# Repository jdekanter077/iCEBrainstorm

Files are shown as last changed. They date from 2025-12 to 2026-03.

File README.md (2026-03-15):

# iCEBrainstorm

A STM32F412 MCU with a iCE40UP5K FPGA on a compact dev board.

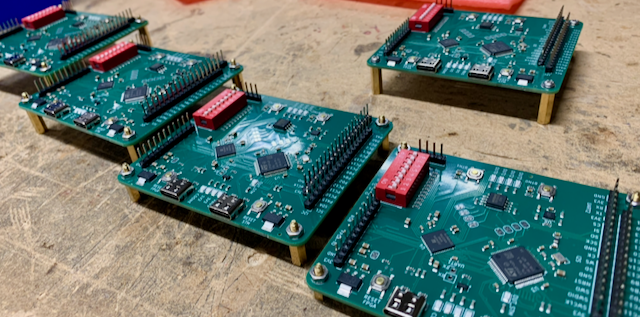
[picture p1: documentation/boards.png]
boards


You will need STMCubeMX, VSCode with the STM32Cube Extension and STMCubeProgrammer to program the STM.

<!-- You can use [apio](https://github.com/FPGAwars/apio) to synthesise a design and upload the firmware to the FPGA using a [online dfu-uploader](https://devanlai.github.io/webdfu/dfu-util/) (easier) -->

<!-- You will need to use the [oss-cad-suite](https://github.com/YosysHQ/oss-cad-suite-build) to to synthesise your design and upload the bitstream to the FPGA.  -->
You can use apio to synthesize and upload your hdl on the FPGA. Refer to [apio support](#apio-support) on how to configure apio to support the iCEBrainstorm board.

## Basic Structure
The STM32 Microcontroller and the iCE40 FPGA share one PCB and have some connections between them to communicate.
They can be programmed through their respective USB-C Port.
There are some switches to select the "program mode" for both the STM and the FPGA.

The code and bootloader of the SMT are stored inside the SMT IC, but the code and bootloader of the FPGA are stored on an external SPI Flash IC. 

There is also an gyrosensor on board. For more documentation, go look at the KiCAD files.

<!-- ![](/documentation/foto.png) -->

## How to Program:
Both the STM and the FPGA use a "Bootloader" to re-program themselfes. This makes the device visible to your computer and puts it in "program mode".

### STM32
The STM32 relies on its build-in bootloader to program itself via USB.
The bootloader is selected by switching the ```BOOT0``` Switch and ```RESET```-ing the SMT:
- Set the ```BOOT0``` Switch
- press ```RESET STM``` or plug in the cable
- The STM is now in DFU-mode, and can be programmed with STM32CubeProgrammer (or other software)
- In CubeProgrammer: select USB and click connect

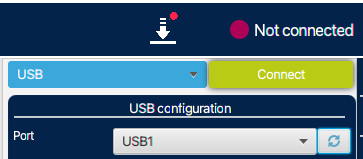
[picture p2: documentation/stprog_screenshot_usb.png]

- Click ```Open File``` and select your ```.elf``` file


- Click ```Download```


- Reset the ```BOOT0``` Switch.
- press ```RESET STM``` and your code should run.

### ICE40 FPGA

The FPGA relies on the [no2 bootloader](https://github.com/psychogenic/no2bootloader/tree/master), which is stored on the SPI-Flash IC.
The bootloader is selected by switching the ```FBOOT``` switch and ```RESET```-ing the FPGA, and then putting the ```FBOOT``` switch back.
Check if the ```CDONE``` LED at the top of the board is on.

- Set the ```FBOOT``` Switch
- press ```RESET FPGA``` or plug in the cable
- Reset the ```BOOT0``` Switch.
- Check if the ```CDONE``` LED at the top of the board is on.
- The FPGA is now in DFU-mode, and can be programmed with 
```apio upload``` or using ```dfu-util```

<!-- - run ```dfu-util -l``` to list all dfu devices. -->
<!-- example output: 
```Found DFU: [1d50:6146] ver=0006, devnum=12, cfg=1, intf=0, path="", alt=1, name="RISC-V firmware", serial="e464bc68932e5839"
Found DFU: [1d50:6146] ver=0006, devnum=12, cfg=1, intf=0, path="", alt=0, name="iCE40 bitstream", serial="e464bc68932e5839"
``` -->
<!-- - run ```dfu-util -d 1d50:6146 -a 0 -D hardware.bin``` to flash your bitstream on the FPGA. Maybe You have to replace the ```1d50:6146```-number with what you see on your terminal. -->
- you can run ```apio devices usb``` to list all dfu devices and verify that everything works.
- run ```apio upload``` to synthesize and upload the verilog code.

-  To edit your HDL code, take a look at the examples in [software/FPGA](./software/FPGA)

### APIO Support
[apio](https://github.com/FPGAwars/apio) is a open-source FPGA Toolchain, which will help us synthesize HDL code.
Make sure you have a recent version of apio installed! You can uninstall and install again to update.
- Install apio using ```pip install apio```
- edit ```~/.apio/packages/definitions/boards.jsonc``` and add this snippet:
```
  // https://github.com/jdekanter077/iCEBrainstorm
  "iCEBrainstorm": {
    "legacy-name": "iCEBrainstorm",
    "description": "iCEBrainstorm by jdk",
    "fpga-id": "ice40up5k-sg48",
    "programmer": {
      "id": "dfu"
    },
    "usb": {
      "vid": "1d50",
      "pid": "6146"
    }
  },
```

This will add apio support for the iCEBrainstorm board.
-  to create a new project, run ```apio create -b iCEBrainstorm```
-  edit your HDL code, take a look at the examples in [software/FPGA](./software/FPGA)

### Bootloader
The Bootloader is preinstalled by Joël and should not have to be touched.
Check out [bootloader/README.md](./software/FPGA/bootloader/README.md) for more information.

## Setting up a blank Project
### STM
- Open CubeMX and select ```File -> New Project```.
- In ```Commercial Part Number```, Type ```STM32F412RET6TR``` and select ```Start Project```.
![](./documentation/stcubemx_newproj.png)
- Select ```RCC_MCO_2``` on ```PB9``` to provide a Clock signal to the FPGA
- Select your desired pins, for example ```PB5```, which is connected to the on-board LED and select ```GPIO_Output```.
![](./documentation/stcubemx_pins.png)
- On the left Pane in ```System Core -> GPIO -> PB5``` set a user label, for example ```OUT_STM```
![](./documentation/stcubemx_gpio.png)
- Set the Input Clock to Cyrstal Oscillator in ```System Core -> RCC```
![](./documentation/stcubemx_sys_clock.png)
- Got to ```Clock Configuration``` at the top and set the Input Frequency of the Clock to 16 MHz
![](./documentation/stcubemx_clock_tree.png)
- Go to ```Project Manager``` on the top.
Make sure to select ```CMake``` as the ```Toolchain / IDE```.
![](./documentation/stcubemx_projman1.png)
Make sure to set ```Generate ... as pair of '.c/.h' files ...```
![](./documentation/stcubemx_projman2.png)

- Save your project and click ```GENRATE CODE``` in the top right and open the folder in VSCode

- Make sure to not miss the notification to "configure CMake Projects as STM32 Projects". click Yes.
![](documentation/vscode_notification.png)

- Select a Preset from the Popup (Debug)
- Edit the Code, for example, add blinky loop in ```Core/Src/main.c```
- ```line 98```:

```
/* USER CODE BEGIN WHILE */
while (1)
  {
    HAL_GPIO_TogglePin(OUT_STM_GPIO_Port, OUT_STM_Pin);
    HAL_Delay(100);
    /* USER CODE END WHILE */

    /* USER CODE BEGIN 3 */
  }
  /* USER CODE END 3 */
}
```
- To Compile the code, go to ```Run & Debug -> Run & Debug -> STM32Cube: STLink GDB Server```

![](documentation/vscode_compile.png)
- This will compile the code, and try to start a "debugger", which is not available and gives a error. The Code should still be compiled correctly!
- Check if you have a ```.elf``` file in ```build/Debug/```. Upload this to the iCEBrainstorm using the steps described in [how-to-programm](#how-to-program)

## Clock
The STM and the FPGA are relatively independent from each other, with one slight caveat:
The STM32 is responsible for providing the FPGA with a Clock signal. The no2-bootloader of the FPGA relies on this clock source, and will not work without it. 

This clock can of course be used in your FPGA design as well.

### How to provide the clock 
- In cubeMX, go to ```PC9``` and select ```RCC_MCO_2```

![](/documentation/stcubemx_rcc_mco_2.png)
- Generate Code, open the folder in STMCubeIDE or VSCode, compile, and upload using STMCubeProgrammer.
- Done!

## FPGA Pinout Description:
These informations should be in every ```main.pcf``` file.

| Description | FPGA Pin | Usage |
| --- | ---- | ---- |
| clk_i | 20  | 16 MHz Clock, provided by the STM32 | 
| btn_0 | 31 | left button | 
| btn_1 | 32 | right button | 
| in_0 | 34 | Input Switch and/or GPIO | 
| in_1 | 35 | Input Switch and/or GPIO | 
| in_2 | 36 | Input Switch and/or GPIO | 
| in_3 | 37 | Input Switch and/or GPIO | 
| out_0 | 25  | LED | 
| out_1 | 26  | LED | 
| out_2 | 27  | LED | 
| out_3 | 28  | LED | 
| io_0 | 47  | GPIO | 
| io_1 | 42  | GPIO | 
| io_2 | 38  | GPIO | 
| io_3 | 23  | GPIO | 
| rgb_0 | 39 | RGB LED and/or GPIO | 
| rgb_1 | 40 | RGB LED and/or GPIO | 
| rgb_2 | 41 | RGB LED and/or GPIO | 
| uart_tx | 2  | uart output (STM RX <- FPGA TX) | 
| uart_rx | 3  | uart input (STM TX -> FPGA RX) | 
| scl | 19 | I2C Clock | 
| sda | 18 | I2C Data | 

# Examples

## FPGA & STM: Morse Encoder
This project implements Morse encoder. The FPGA encodes the Morse Code, and sends the encoded character over UART to the STM.
The STM then sends the recieved character over USB to the host machine.

- upload ```./software/STM/uart_serial_bridge``` to the STM.
- upload ```./software/FPGA/morse_uart``` to the FPGA.
- open a serial monitor and have fun!

for details: take a look at the [Readme](./software/FPGA/morse_uart/README.md)

## STM: uart-serial Bridge

This project implements a UART-Serial bridge. The STM sends all recieved uart messages over usb to the host machine, and sends all recieved usb messages over usb to the FPGA.
This is done by using an Interrupt-driven approach.

snippet:

## FPGA: bram
[bram](./software/FPGA/bram)

This example of how to instintiate a one of the build-in BRAMs on the FPGA is based on [this repo](https://github.com/damdoy/ice40_ultraplus_examples/tree/master/bram) and on the [online documentation](https://www.latticesemi.com/~/media/LatticeSemi/Documents/ApplicationNotes/MO/MemoryUsageGuideforiCE40Devices.pdf)
It uses the switches IN0-IN3 as input "data" and loads it into the bram using btn0. Using btn1, the "data" can then be displayed on the leds.

# Author
Joël de Kanter

# License

This repository is primarily licensed under the GNU General Public License v3.0.

Exceptions:
- STM32CubeMX-generated files are licensed under STMicroelectronics'
  STM32Cube firmware license (see file headers).
- The NO2 bootloader firmware is licensed under GPL-3.0-or-later
- Some third-party components may be licensed under MIT or CERN OHL v2.

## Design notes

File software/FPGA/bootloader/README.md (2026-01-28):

# BOOTLOADER

The FPGA relies on the no2bootloader to make itself flashable over USB.

This process was inspired by a [youtube video](https://www.youtube.com/watch?v=gGN0g9jgsUc)

## How to build the bootloader
### Installing depencies
Don't even try building when until these are installed and can be called from your terminal!
- install the [oss-cad-suite](https://github.com/YosysHQ/oss-cad-suite-build)
- install a [embedded riscv compiler (xpack)](https://xpack-dev-tools.github.io/riscv-none-elf-gcc-xpack/)
- for the riscv-compiler, you'll need [xpm](https://xpack.github.io/xpm/)
- and for that, you'll need [npn](https://docs.npmjs.com/cli/v11/configuring-npm/install)

### make sure to set the $PATH
example:
```
export PATH=$PATH:/Users/oompje_joost/fpga-toolchain/bin:/Users/oompje_joost/oss-cad-suite/bin
export PATH=$HOME/Library/xPacks/@xpack-dev-tools/riscv-none-elf-gcc/15.2.0-1.1/.content/bin:$PATH
export PATH=$PATH:/usr/local/Cellar/flashrom/1.6.0/sbin/
```
consider setting them permanently by adding this to the end of your ```.bashrc``` file.

### Compiling
go to ```no2bootloader/ice40-stub/```

run ```make PRE_CLEAN=1 bootloader-clean``` to cleanup the old files.

run ```make BOARD=icebrainstorm CROSS=riscv-none-elf- bootloader``` to build the bootloader.

If everything works, a ```bootloader.bin``` file should be generated in ```ice40-stub/build-tmp```. This needs to be moved ino the flash.

## Flashing the bootloader to the FPGA

If the no2bootloader is (still) in the spi-flash, than switch the ```FBOOT``` button 4 times. The Bootloader should show up in ```dfu-util -l```. There should be 4 options/listed devices istead of the usual two. If this works, you can update the Bootloader using ````dfu-util```.
Else:

### Preparing the Board
Electrically disconnect the spi-flash from the FPGA by desoldering + cutting the connections of the SPI lines. Make sure (with a mutimeter) that the connections are indeed not conducting.

### Preparing the Programmer
Connect a second device (I used a raspberry pi pico) to act as SPI Programmer. Compile and flash the code on the pico.

[Pico code](https://github.com/stacksmashing/pico-serprog#readme)

### Flashing
- install ```flashrom```
- make sure to add it to your ```$PATH```

because the binairy file is not exactly as big as the SPI flash, flashrom will complain..

- Add a ```layout.txt``` file to tell flashrom what it needs to flash.

Content of layout.txt: ```00000000:00061ACF bootloader```
replace the hex number with the size of ```hardware.bin``` (in hexadecimal) minus one.

run ```flashrom -p serprog:dev=/dev/tty.usbmodem1301:115200,spispeed=12M --layout layout.txt --include bootloader:bootloader.bin -w``` 
the usb device may differ a bit. 

# Author
Joël de Kanter

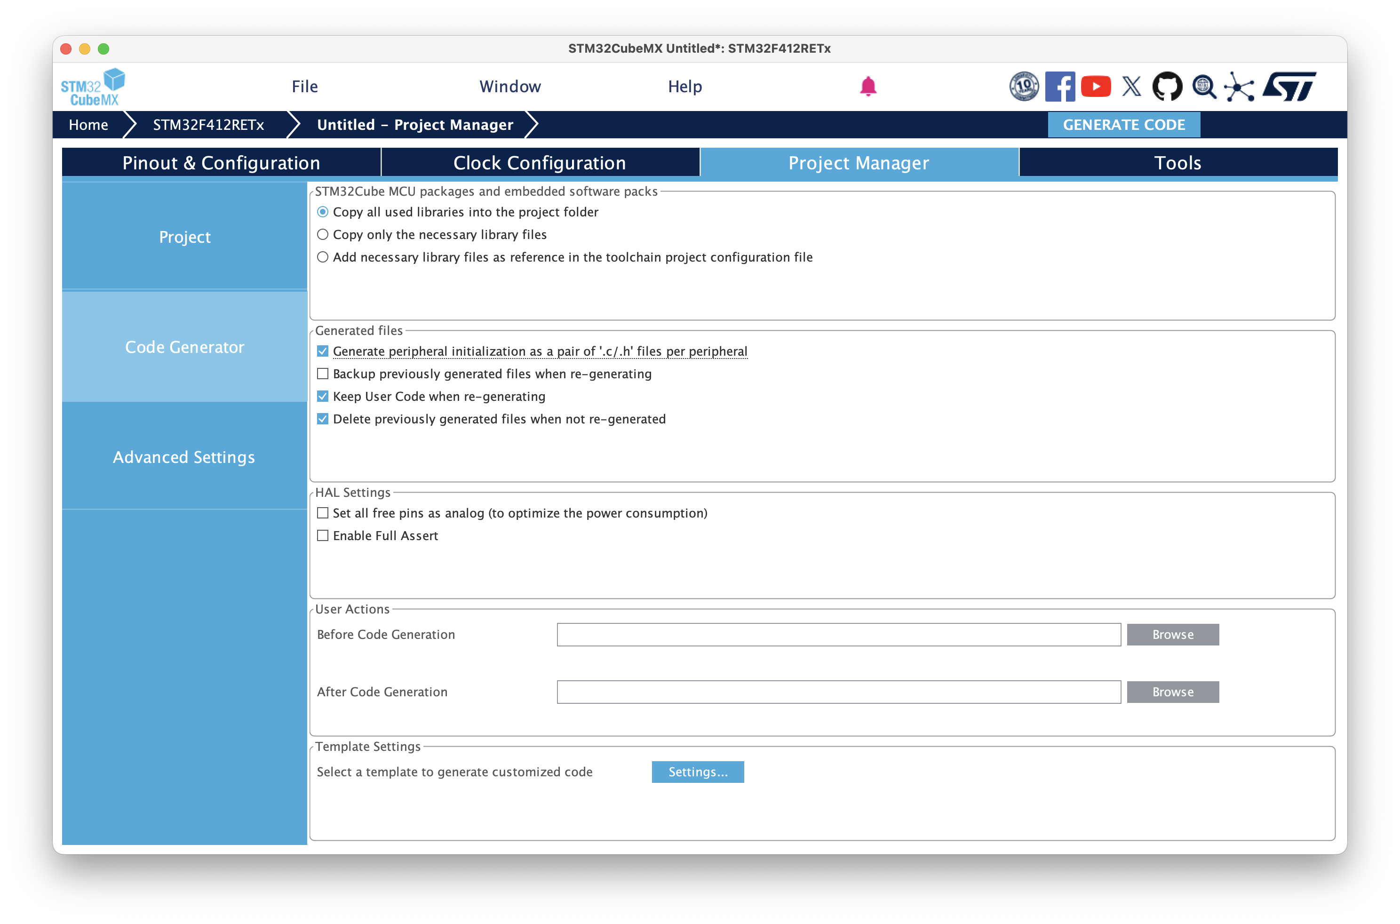
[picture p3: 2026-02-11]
documentation/stcubemx_projman2.png

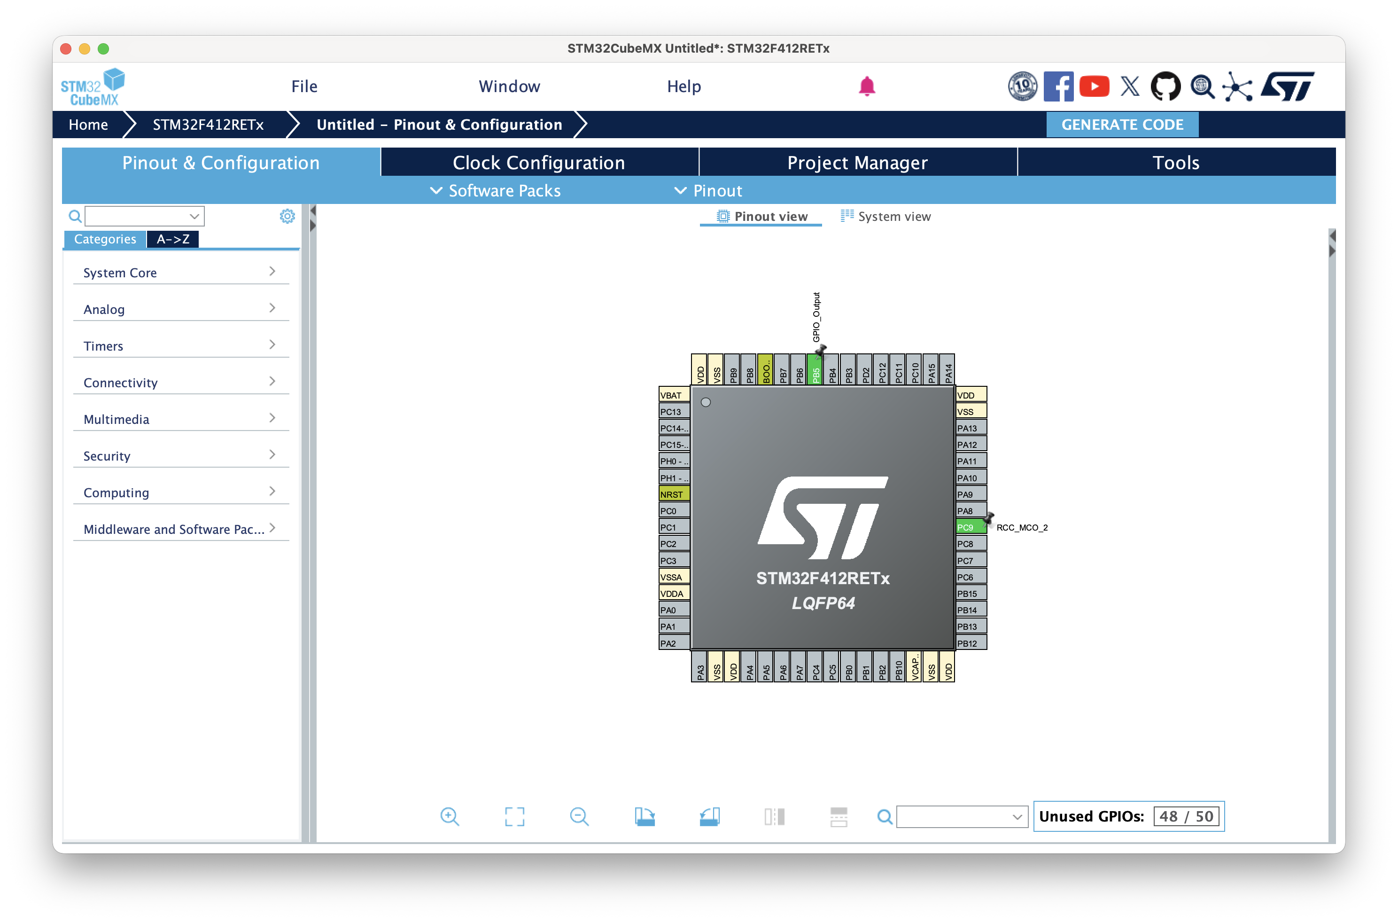
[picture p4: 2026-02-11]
documentation/stcubemx_pins.png

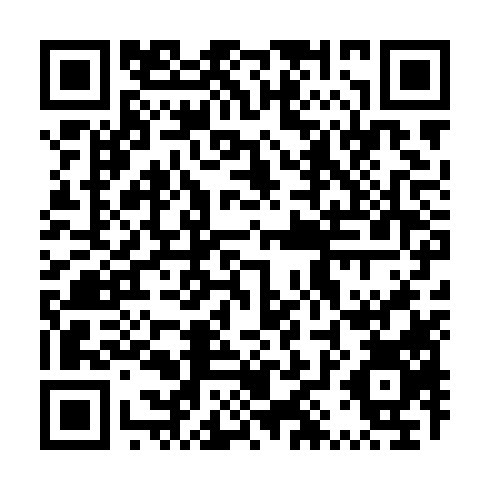
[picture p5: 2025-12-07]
documentation/qr.png

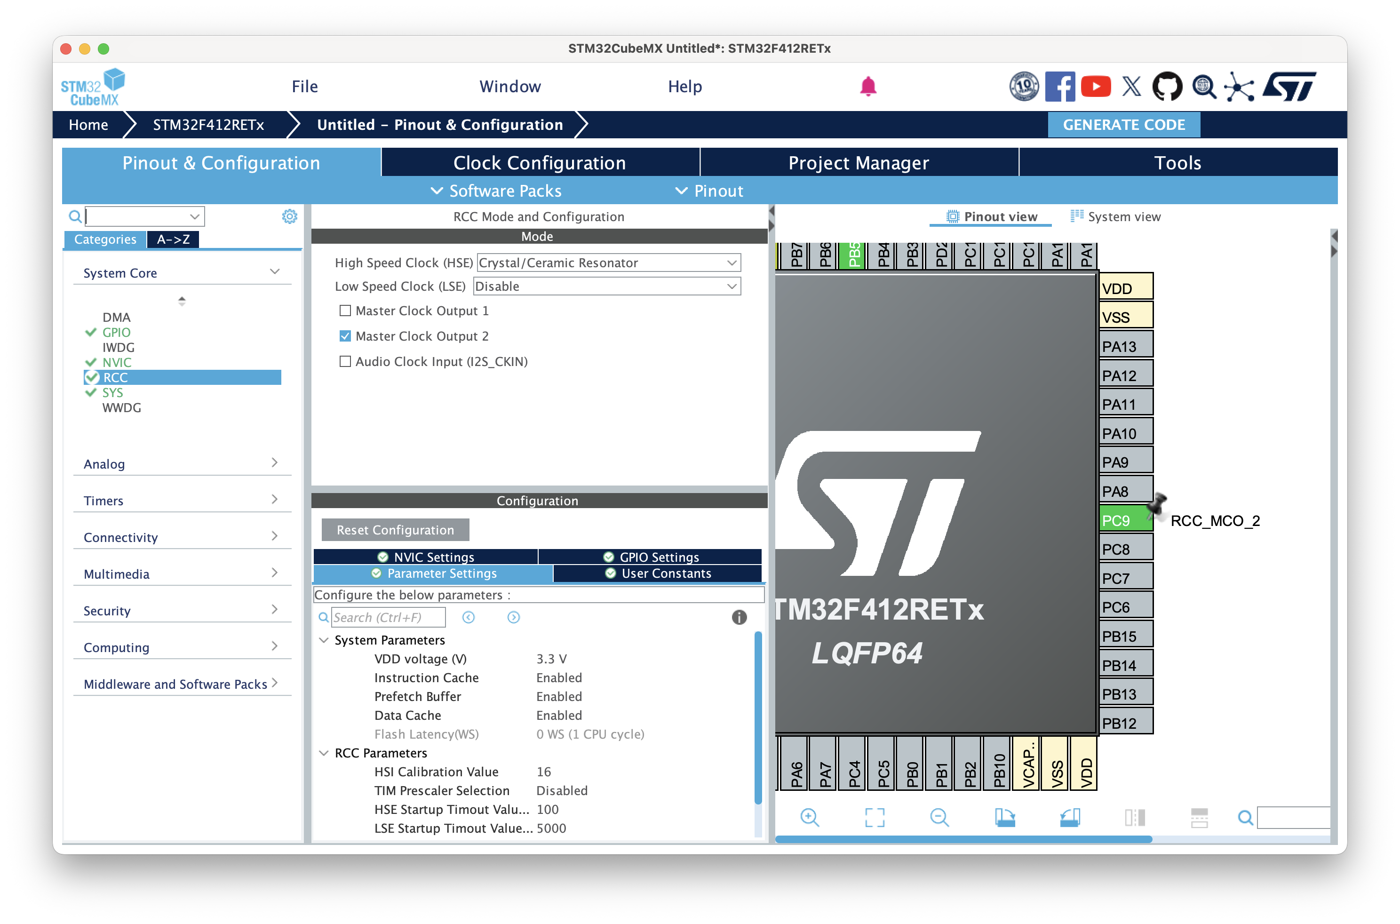
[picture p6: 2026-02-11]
documentation/stcubemx_sys_clock.png

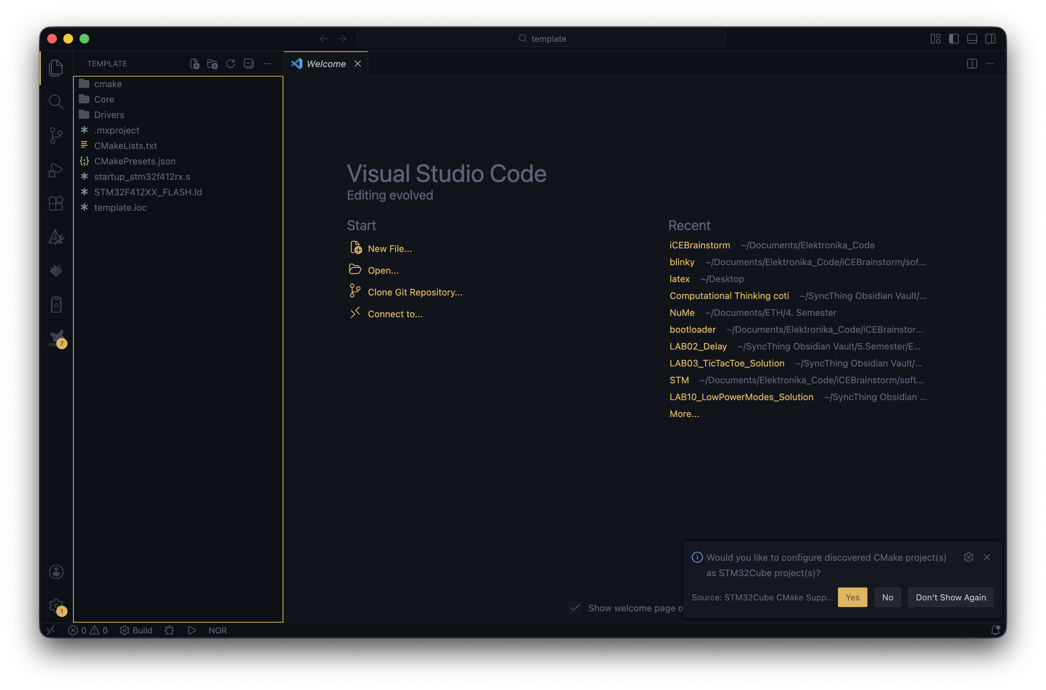
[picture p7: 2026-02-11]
documentation/vscode_notification.png

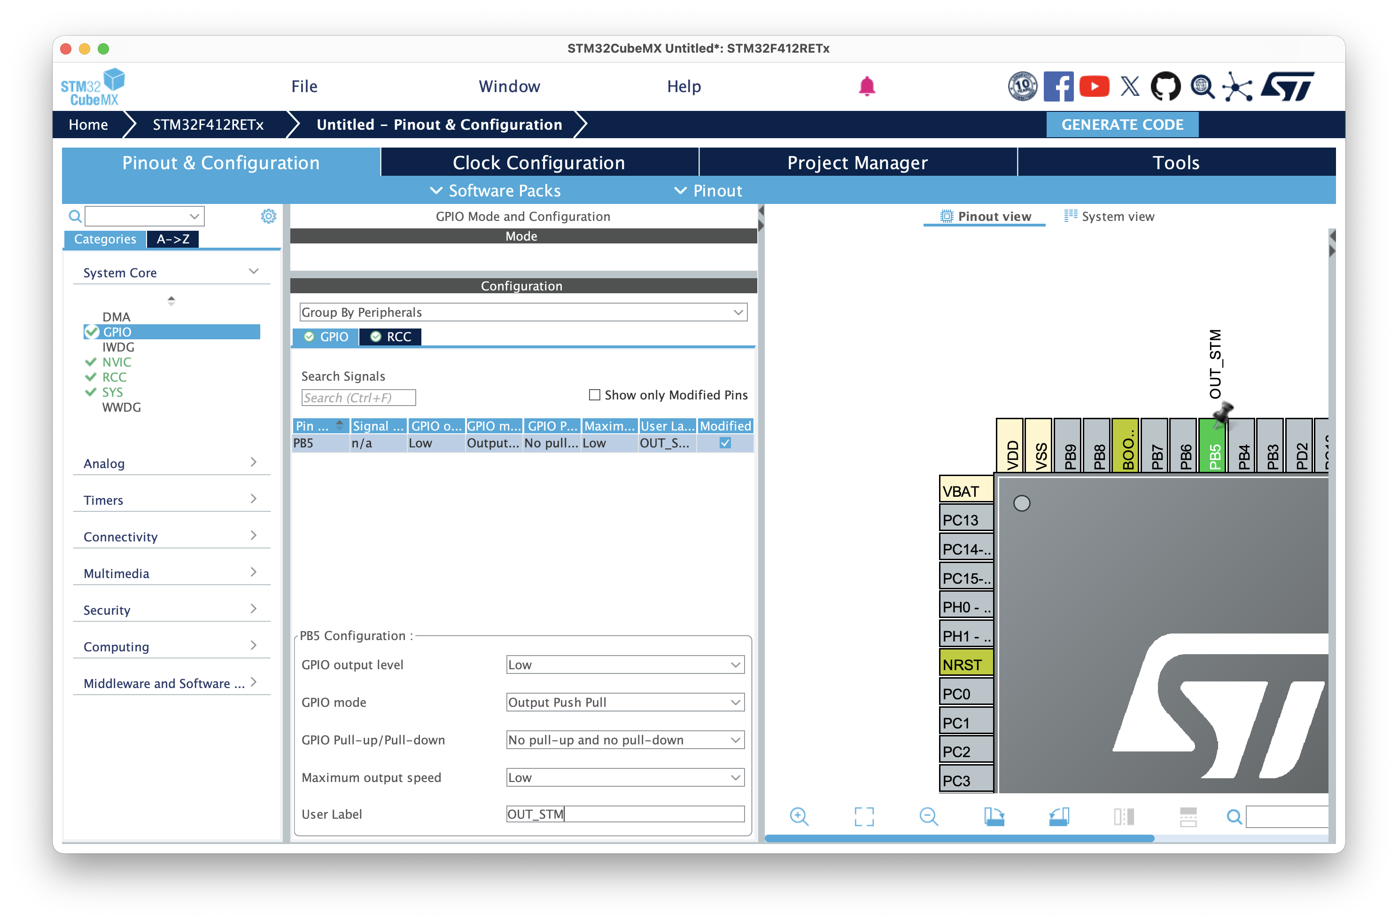
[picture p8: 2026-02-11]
documentation/stcubemx_gpio.png

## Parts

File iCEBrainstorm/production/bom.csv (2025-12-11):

Designator | Footprint | Quantity | Value | LCSC Part #
C1, C2, C3, C4 | C_0805 | 4 | 22uF | C45783
C10, C11, C12, C13, C14, C24, C25, C26, C27, C30, C31, C33, C34, C6, C7, C8 | C_0603 | 16 | 100nF | C14663
C15, C22, C23, C29, C5, C9 | C_0805 | 6 | 4.7uF | C1779
C16, C18, C28, C32 | C_0603 | 4 | 1uF | C15849
C17, C20 | C_0603 | 2 | 10pF | C1634
C19 | C_0603 | 1 | 10nF | C57112
D1 | D_0805 | 1 | 1V2 ON - Green | C2297
D2 | D_0805 | 1 | 3V3 ON - Green | C2297
D3 | D_0805 | 1 | VBUS ON - Green | C2297
D4 | D_0805 | 1 | Configuration Ready - Green | C2297
D5, D6, D7, D8, D9 | D_0805 | 5 | Green | C2297
FB1 | FB_0805 | 1 | ~ | C1017
J1, J16 | TYPE-C-SMD_HX-TYPE-C-16PIN | 2 | Connector, USB-TYPE-C-16P | C2927039
J10, J9 | PinHeader_1x03_P2.54mm_Vertical | 2 | Conn_01x03_Pin
J11, J7 | PinHeader_1x04_P2.54mm_Vertical | 2 | Conn_01x04_Pin
J12, J13, J14, J4, J5, J6 | PinHeader_1x02_P2.54mm_Vertical | 6 | Conn_01x02_Pin
J15, J3 | PinHeader_1x06_P2.54mm_Vertical | 2 | Conn_01x06_Pin
J2 | PinHeader_1x16_P2.54mm_Vertical | 1 | Conn_01x16_Pin
N1 | iCE-Brain | 1 | Housing, iCE-Brain Silkscreen
PN1 | Part_Num_JLCPCB | 1 | iCEBrainrot
Q1 | Q_SOT-23 | 1 | HL2312 | C28646272
R1, R10, R11, R12, R13, R14, R21, R28, R29, R31, R32, R8, R9 | R_0603 | 13 | 15kΩ | C22809
R15, R16, R17, R18, R19, R2, R20, R23, R24, R25, R26, R27, R30, R33, R34, R35, R36, R40, R41, R5, R6 | R_0603 | 21 | 1.5kΩ | C22843
R22 | R_0603 | 1 | 2.2kΩ | C4190
R3, R37, R38, R4 | R_0603 | 4 | 5.1kΩ | C23186
R42, R43 | R_0603 | 2 | 68Ω | C27592
R7 | R_0603 | 1 | 100Ω | C22775
S1, S2, S3, S4 | SW-SMD_4P-L5.1-W5.1-P3.70-LS6.5-TL-2 | 4 | RESET | C318884
SW1 | SW_DIP_SPSTx08_Slide_6.7x21.88mm_W7.62mm_P2.54mm_LowProfile | 1 | SW_DIP_x08
U1 | SOT-223-3_L6.5-W3.4-P2.30-LS7.0-BR | 1 | AMS1117-3.3 | C6186
U2 | SOT-223-3_L6.5-W3.4-P2.30-LS7.0-BR | 1 | AMS1117-1.2 | C14529
U3 | LQFP-64_10x10mm_P0.5mm | 1 | STM32F412RETx | C89374
U4 | QFN-48-1EP_7x7mm_P0.5mm_EP5.6x5.6mm | 1 | ICE40UP5K-SG48ITR | C2678152
U5 | SOIC-8_L5.3-W5.3-P1.27-LS8.0-BL | 1 | W25Q128 | C97521
U6 | LGA-14_3x2.5mm_P0.5mm_LayoutBorder3x4y | 1 | LSM6DS3
X1 | OSC-SMD_4P-L3.2-W2.5-BL | 1 | 16 MHz | C13738

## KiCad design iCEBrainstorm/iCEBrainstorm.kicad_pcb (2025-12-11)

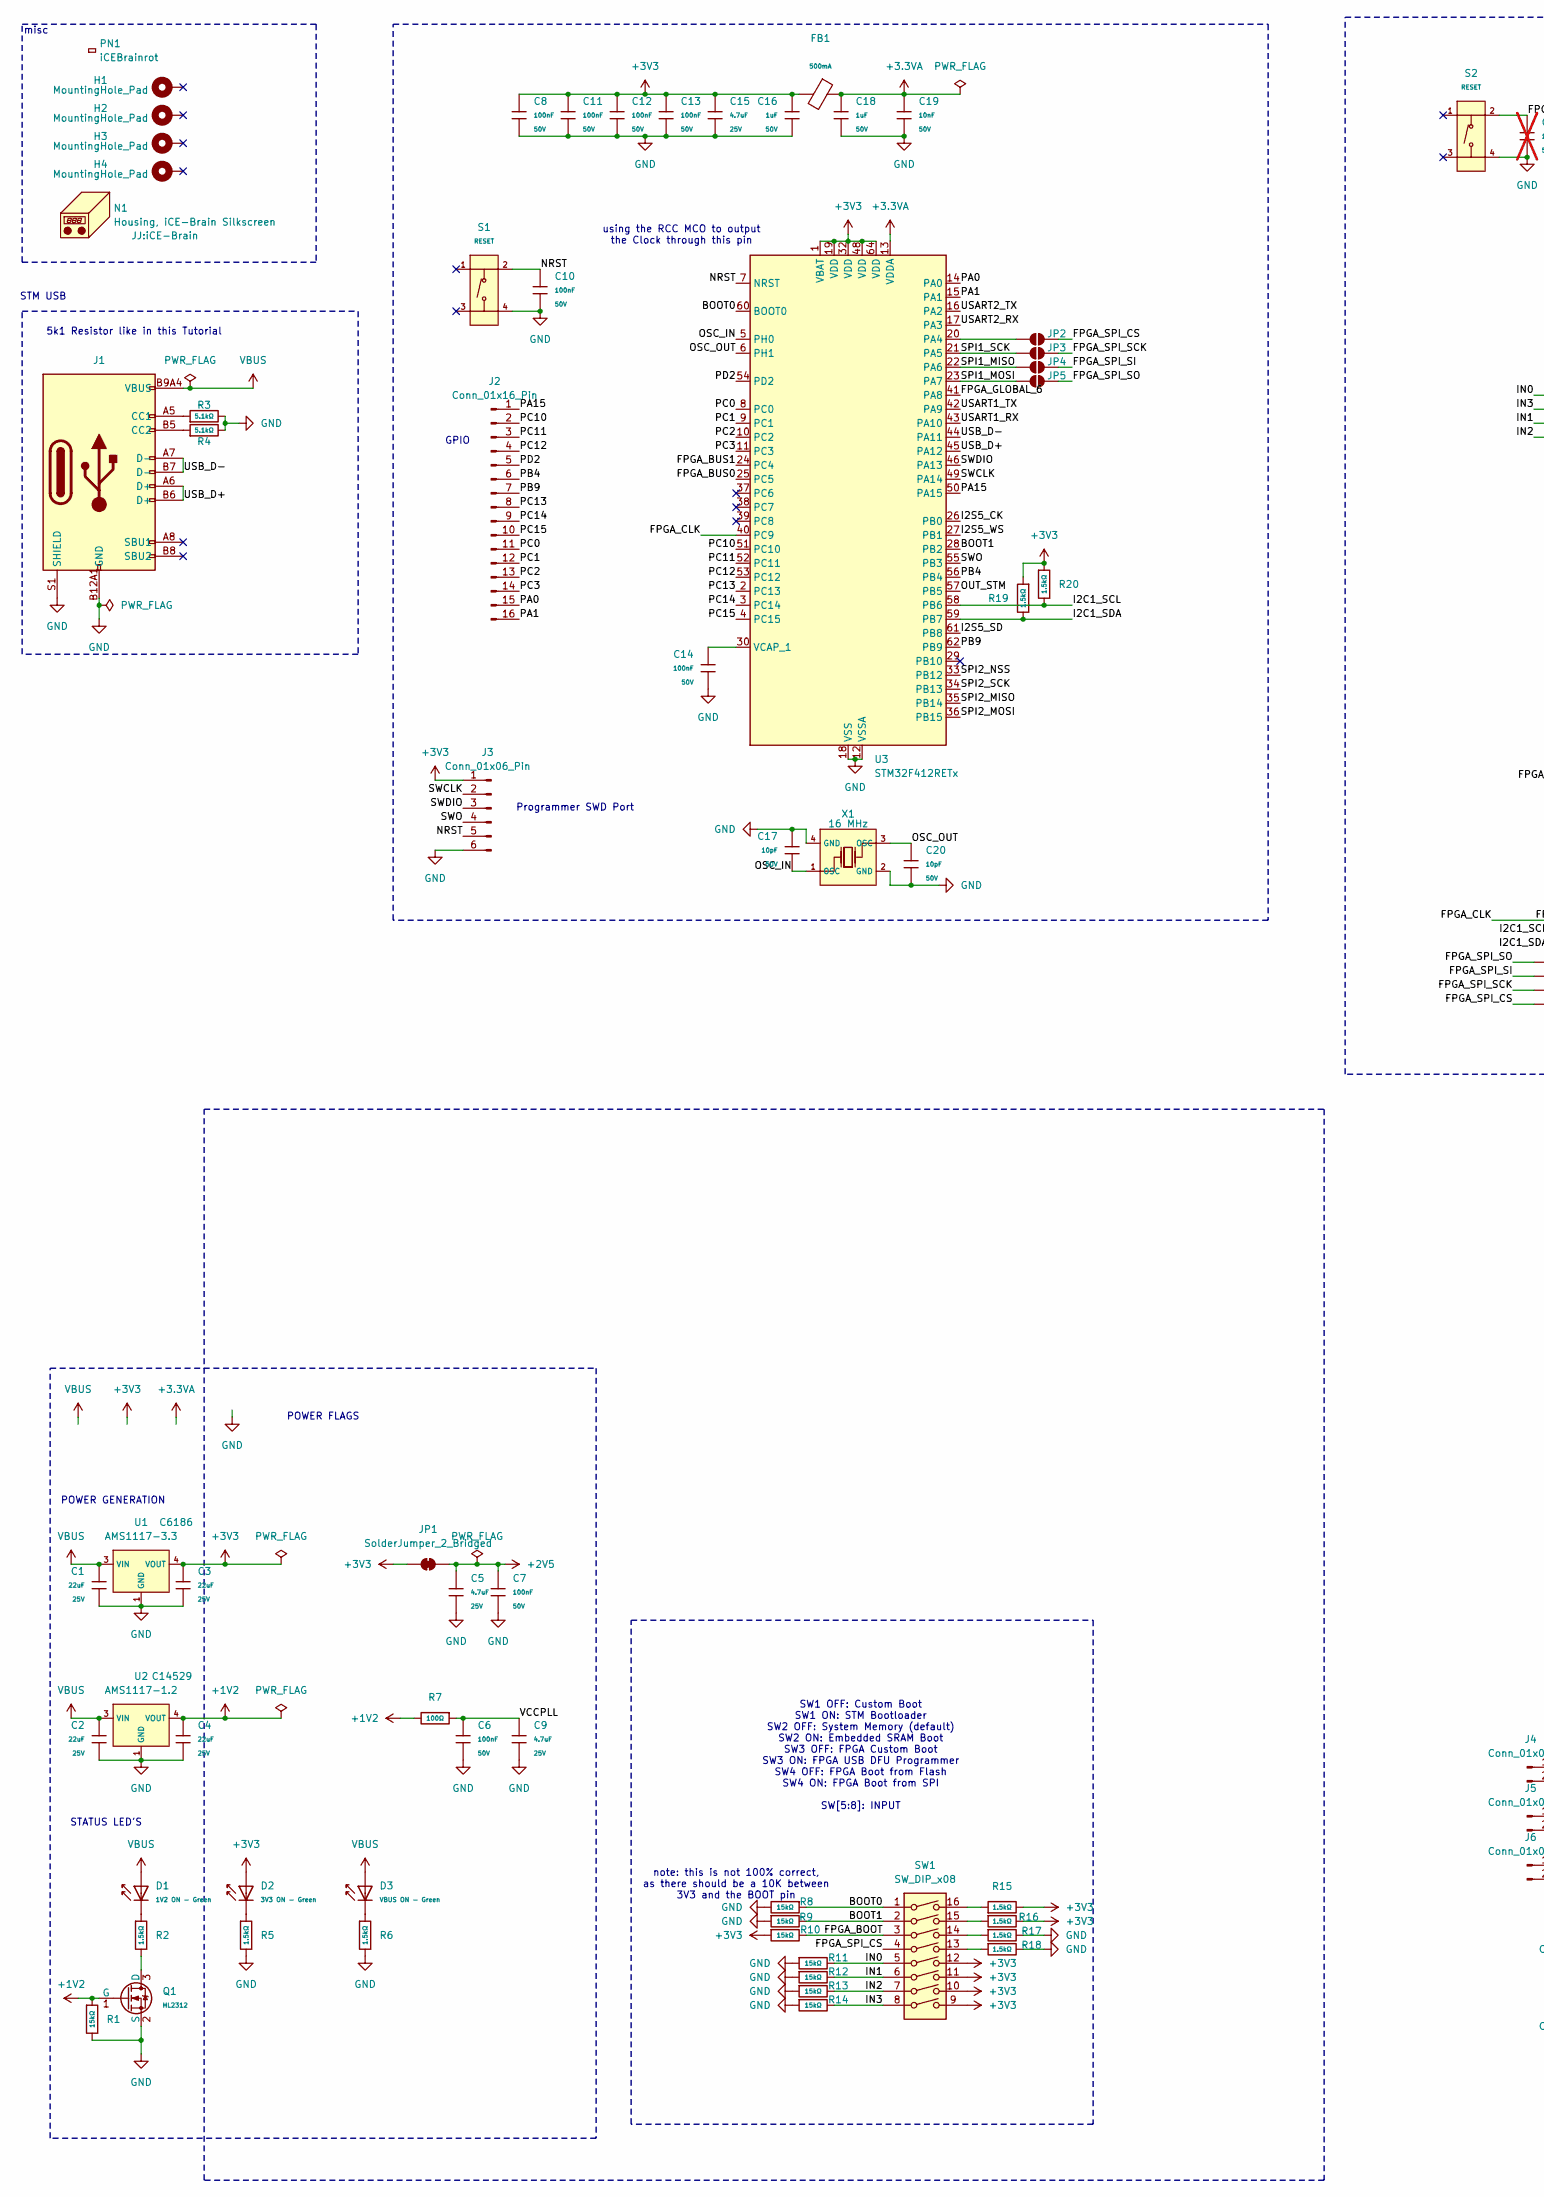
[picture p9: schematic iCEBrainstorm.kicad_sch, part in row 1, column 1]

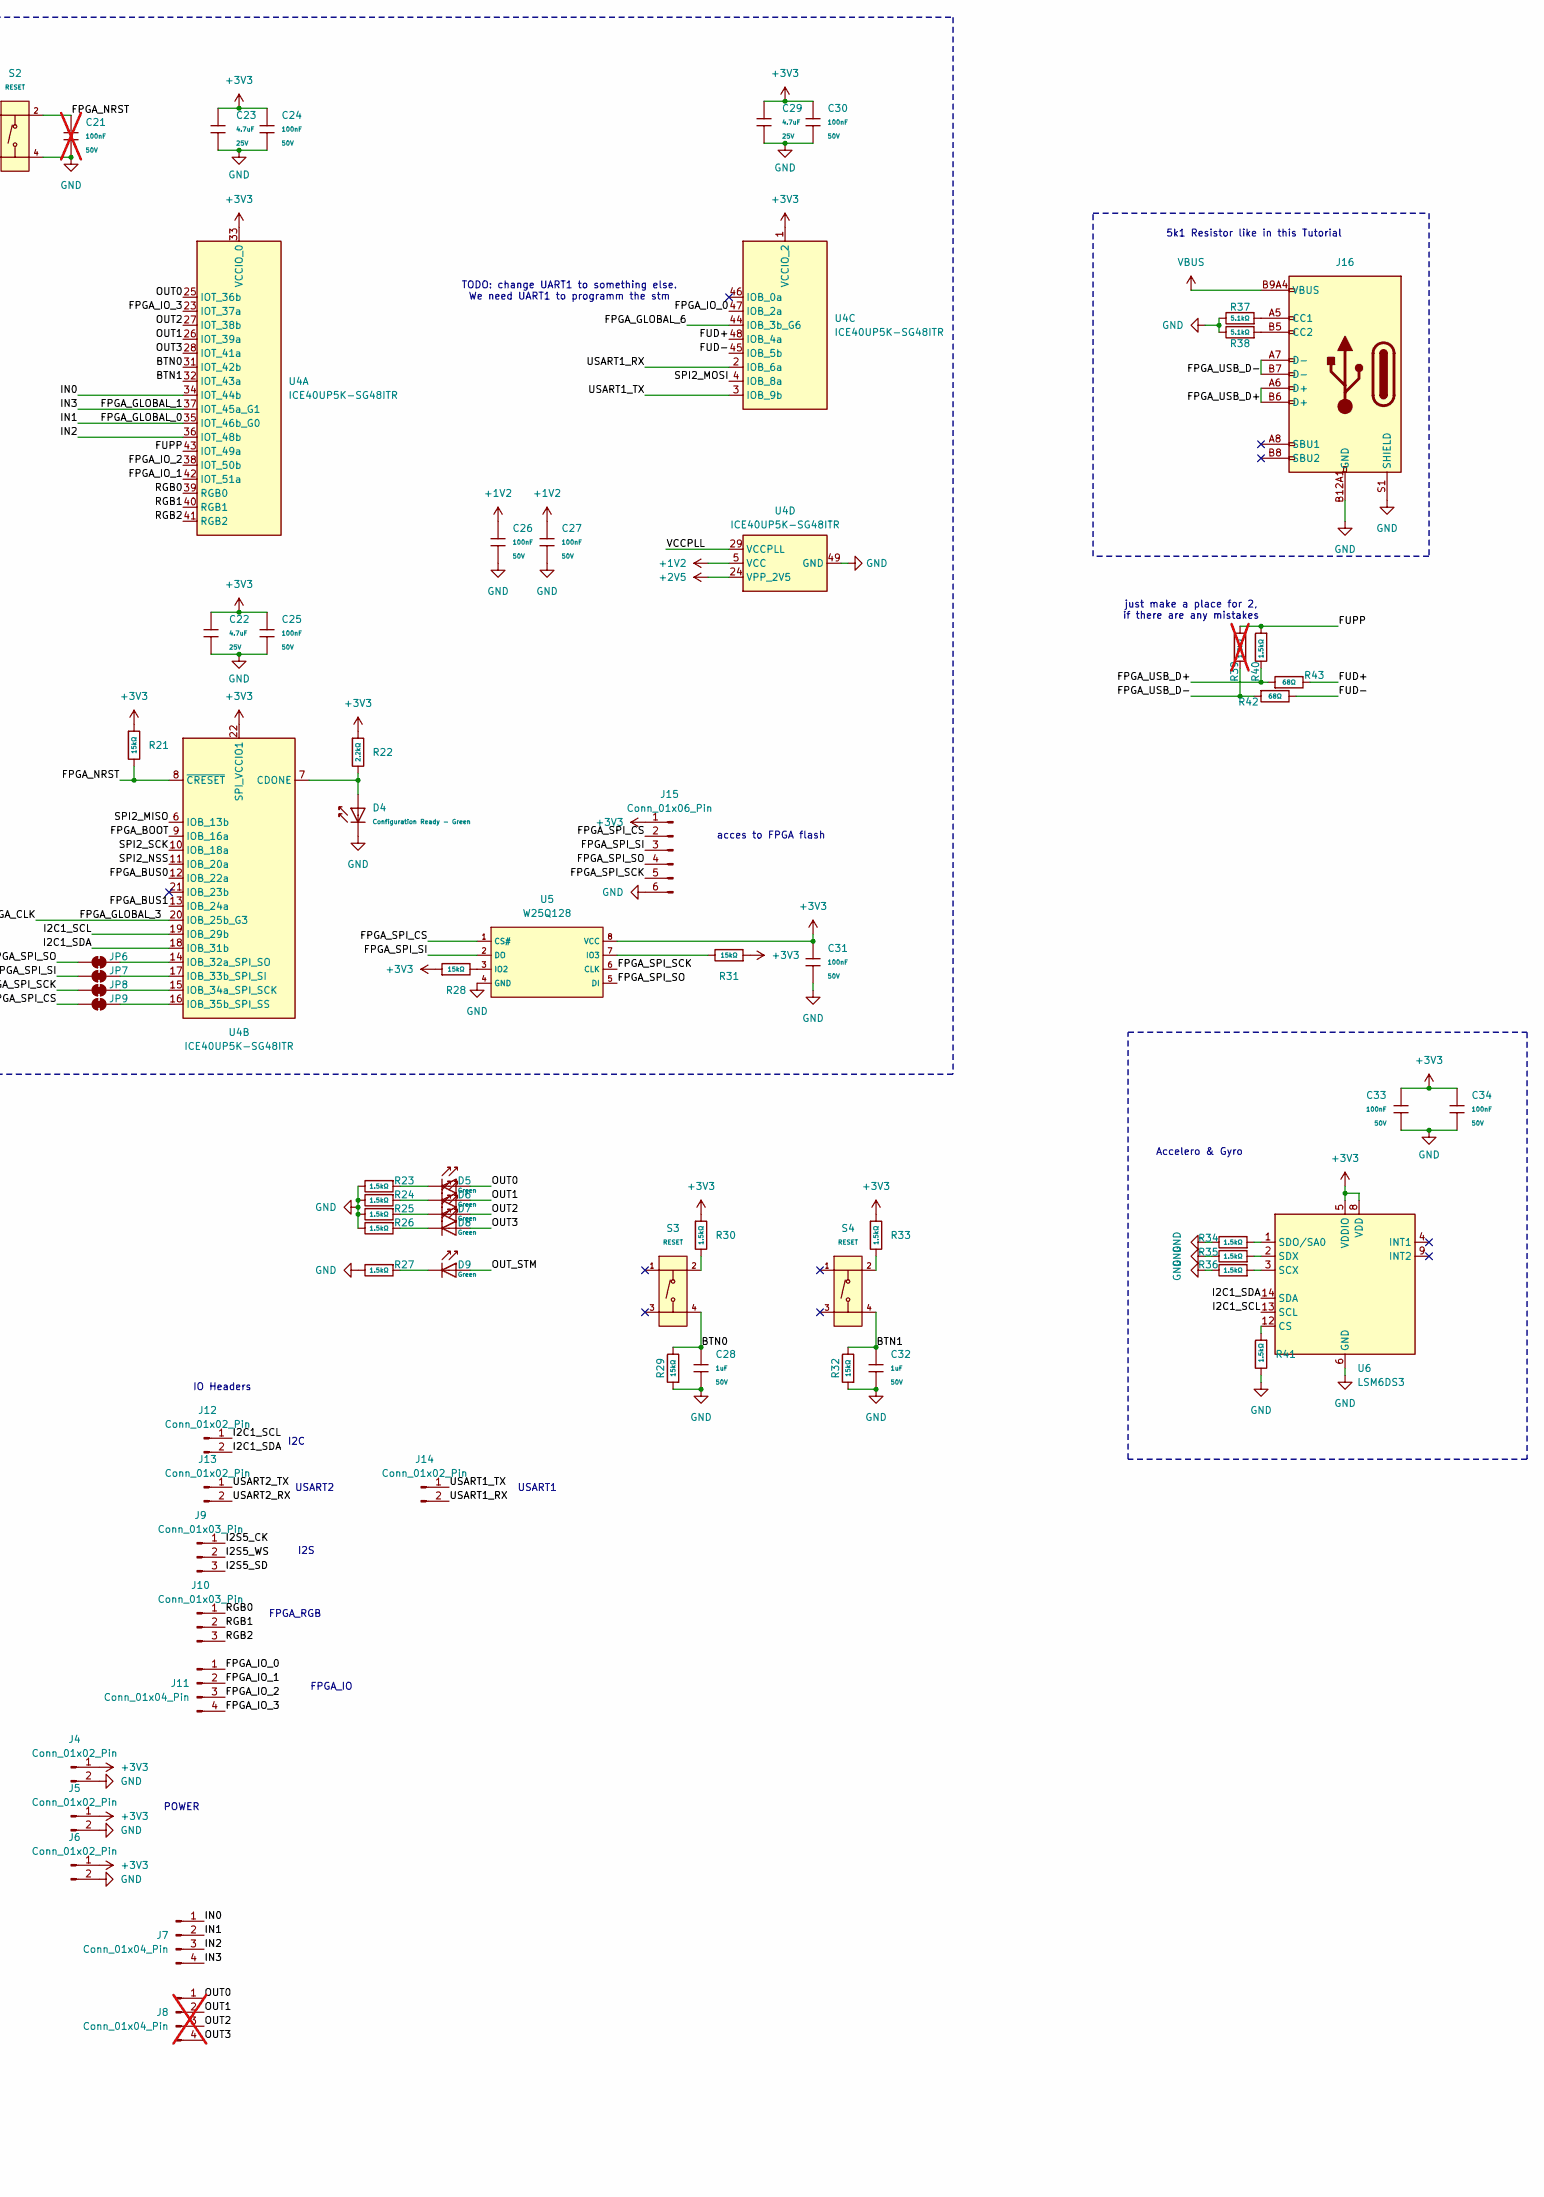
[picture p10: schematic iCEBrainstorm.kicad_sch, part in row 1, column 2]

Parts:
C1, C2, C3, C4: 22uF; C_0805; Voltage Rated 25V; Tolerance ±20%; Part CL21A226MAQNNNE; LCSC C45783
C5, C9, C15, C22, C23, C29: 4.7uF; C_0805; Voltage Rated 25V; Tolerance ±10%; Part CL21A475KAQNNNE; LCSC C1779
C6, C7, C8, C10, C11, C12, C13, C14, C24, C25, C26, C27, C30, C31, C33, C34: 100nF; C_0603; Voltage Rated 50V; Tolerance ±10%; Part CC0603KRX7R9BB104; LCSC C14663
C16, C18, C28, C32: 1uF; C_0603; Voltage Rated 50V; Tolerance ±10%; Part CL10A105KB8NNNC; LCSC C15849
C17, C20: 10pF; C_0603; Voltage Rated 50V; Tolerance ±5%; Part CL10C100JB8NNNC; LCSC C1634
C19: 10nF; C_0603; Voltage Rated 50V; Tolerance ±10%; Part 0603B103K500NT; LCSC C57112
C21: 100nF; C_0603; Voltage Rated 50V; Tolerance ±10%; Part CC0603KRX7R9BB104; LCSC C14663; not fitted
D1: 1V2 ON - Green; D_0805; Part KT-0805G; LCSC C2297
D2: 3V3 ON - Green; D_0805; Part KT-0805G; LCSC C2297
D3: VBUS ON - Green; D_0805; Part KT-0805G; LCSC C2297
D4: Configuration Ready - Green; D_0805; Part KT-0805G; LCSC C2297
D5, D6, D7, D8, D9: Green; D_0805; Part KT-0805G; LCSC C2297
FB1: FB_0805; Current Rating 500mA; Tolerance ±25%; Part GZ2012D601TF; LCSC C1017
H1, H2, H3, H4: MountingHole_Pad; MountingHole_2.7mm_Pad
J1, J16: Connector, USB-TYPE-C-16P; TYPE-C-SMD_HX-TYPE-C-16PIN; LCSC C2927039
J2: Conn_01x16_Pin; PinHeader_1x16_P2.54mm_Vertical
J3, J15: Conn_01x06_Pin; PinHeader_1x06_P2.54mm_Vertical
J4, J5, J6, J12, J13, J14: Conn_01x02_Pin; PinHeader_1x02_P2.54mm_Vertical
J7, J11: Conn_01x04_Pin; PinHeader_1x04_P2.54mm_Vertical
J8: Conn_01x04_Pin; PinHeader_1x04_P2.54mm_Vertical; not fitted
J9, J10: Conn_01x03_Pin; PinHeader_1x03_P2.54mm_Vertical
JP1, JP6, JP7, JP8, JP9: SolderJumper_2_Bridged; SolderJumper-2_P1.3mm_Bridged_RoundedPad1.0x1.5mm
JP2, JP3, JP4, JP5: SolderJumper_2_Open; SolderJumper-2_P1.3mm_Open_RoundedPad1.0x1.5mm
N1: Housing, iCE-Brain Silkscreen; iCE-Brain
PN1: iCEBrainrot; Part_Num_JLCPCB
Q1: HL2312; Q_SOT-23; Part HL2312; LCSC C28646272
R1, R8, R9, R10, R11, R12, R13, R14, R21, R28, R29, R31, R32: 15kΩ; R_0603; Overload Voltage (Max) 75V; Tolerance ±1%; Part 0603WAF1502T5E; LCSC C22809
R2, R5, R6, R15, R16, R17, R18, R19, R20, R23, R24, R25, R26, R27, R30, R33, R34, R35, R36, R40, R41: 1.5kΩ; R_0603; Overload Voltage (Max) 75V; Tolerance ±1%; Part 0603WAF1501T5E; LCSC C22843
R3, R4, R37, R38: 5.1kΩ; R_0603; Overload Voltage (Max) 75V; Tolerance ±1%; Part 0603WAF5101T5E; LCSC C23186
R7: 100Ω; R_0603; Overload Voltage (Max) 75V; Tolerance ±1%; Part 0603WAF1000T5E; LCSC C22775
R22: 2.2kΩ; R_0603; Overload Voltage (Max) 75V; Tolerance ±1%; Part 0603WAF2201T5E; LCSC C4190
R39: 1.5kΩ; R_0603; Overload Voltage (Max) 75V; Tolerance ±1%; Part 0603WAF1501T5E; LCSC C22843; not fitted
R42, R43: 68Ω; R_0603; Overload Voltage (Max) 75V; Tolerance ±1%; Part 0603WAF680JT5E; LCSC C27592
S1, S2, S3, S4: RESET; SW-SMD_4P-L5.1-W5.1-P3.70-LS6.5-TL-2; Voltage Rating (Dc) 12V; Part TS-1187A-B-A-B; LCSC C318884
SW1: SW_DIP_x08; SW_DIP_SPSTx08_Slide_6.7x21.88mm_W7.62mm_P2.54mm_LowProfile
U1: AMS1117-3.3; SOT-223-3_L6.5-W3.4-P2.30-LS7.0-BR; Output Voltage 3.3V; Dropout Voltage 1.3V@(800mA); Part AMS1117-3.3; LCSC C6186
U2: AMS1117-1.2; SOT-223-3_L6.5-W3.4-P2.30-LS7.0-BR; Output Voltage 3.3V; Dropout Voltage 1.3V@(800mA); Part AMS1117-3.3; LCSC C14529
U3: STM32F412RETx; LQFP-64_10x10mm_P0.5mm
U4: ICE40UP5K-SG48ITR; QFN-48-1EP_7x7mm_P0.5mm_EP5.6x5.6mm
U5: W25Q128; SOIC-8_L5.3-W5.3-P1.27-LS8.0-BL; Part W25Q128JVSIQ; LCSC C97521
U6: LSM6DS3; LGA-14_3x2.5mm_P0.5mm_LayoutBorder3x4y
X1: 16 MHz; OSC-SMD_4P-L3.2-W2.5-BL; Frequency Tolerance ±10ppm; Part X322516MLB4SI; LCSC C13738

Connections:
+1V2: C4.2, C26.1, C27.1, Q1.1 (G), R1.1, R7.2, U2.2 (VOUT), U2.4 (VOUT), U4.5 (VCC), U4.30 (VCC)
+2V5: C5.1, C7.1, JP1.2 (B), U4.24 (VPP_2V5)
+3.3VA: C18.1, C19.1, FB1.1, U3.13 (VDDA)
+3V3: C3.2, C8.1, C11.1, C12.1, C13.1, C15.1, C16.1, C22.1, C23.1, C24.1, C25.1, C29.1, C30.1, C31.1, C33.1, C34.1, D2.2, FB1.2, J3.1, J4.1, J5.1, J6.1, J15.1, JP1.1 (A), R10.1, R15.2, R16.2, R19.1, R20.1, R21.1, R22.1, R28.1, R30.1, R31.1, R33.1, SW1.9, SW1.10, SW1.11, SW1.12, U1.2 (VOUT), U1.4 (VOUT), U3.1 (VBAT), U3.19 (VDD), U3.32 (VDD), U3.48 (VDD), U3.64 (VDD), U4.1 (VCCIO_2), U4.22 (SPI_VCCIO1), U4.33 (VCCIO_0), U5.8 (VCC), U6.5 (VDDIO), U6.8 (VDD)
/BOOT0: R8.1, SW1.1, U3.60 (BOOT0)
/BOOT1: R9.2, SW1.2, U3.28 (PB2)
/BTN0: C28.1, R29.2, S3.4 (D), U4.31 (IOT_42b)
/BTN1: C32.1, R32.2, S4.4 (D), U4.32 (IOT_43a)
/FPGA_BOOT: R10.2, SW1.3, U4.9 (IOB_16a)
/FPGA_BUS0: U3.25 (PC5), U4.12 (IOB_22a)
/FPGA_BUS1: U3.24 (PC4), U4.13 (IOB_24a)
/FPGA_CLK: U3.40 (PC9), U4.20 (IOB_25b_G3)
/FPGA_GLOBAL_0: J7.2, R12.2, SW1.6, U4.35 (IOT_46b_G0)
/FPGA_GLOBAL_1: J7.4, R14.2, SW1.8, U4.37 (IOT_45a_G1)
/FPGA_GLOBAL_6: U3.41 (PA8), U4.44 (IOB_3b_G6)
/FPGA_IO_0: J11.1, U4.47 (IOB_2a)
/FPGA_IO_1: J11.2, U4.42 (IOT_51a)
/FPGA_IO_2: J11.3, U4.38 (IOT_50b)
/FPGA_IO_3: J11.4, U4.23 (IOT_37a)
/FPGA_NRST: C21.1, R21.2, S2.2 (B), U4.8 (~CRESET)
/FPGA_SPI_CS: J15.2, JP2.2 (B), JP9.1 (A), SW1.4, U5.1 (CS#)
/FPGA_SPI_SCK: J15.5, JP3.2 (B), JP8.1 (A), U5.6 (CLK)
/FPGA_SPI_SI: J15.3, JP4.2 (B), JP7.1 (A), U5.2 (DO)
/FPGA_SPI_SO: J15.4, JP5.2 (B), JP6.1 (A), U5.5 (DI)
/FPGA_USB_D+: J16.A6 (D+), J16.B6 (D+), R40.2, R43.1
/FPGA_USB_D-: J16.A7 (D-), J16.B7 (D-), R39.2, R42.1
/FUD+: R43.2, U4.48 (IOB_4a)
/FUD-: R42.2, U4.45 (IOB_5b)
/FUPP: R39.1, R40.1, U4.43 (IOT_49a)
/I2C1_SCL: J12.1, R20.2, U3.58 (PB6), U4.19 (IOB_29b), U6.13 (SCL)
/I2C1_SDA: J12.2, R19.2, U3.59 (PB7), U4.18 (IOB_31b), U6.14 (SDA)
/I2S5_CK: J9.1, U3.26 (PB0)
/I2S5_SD: J9.3, U3.61 (PB8)
/I2S5_WS: J9.2, U3.27 (PB1)
/IN0: J7.1, R11.2, SW1.5, U4.34 (IOT_44b)
/IN2: J7.3, R13.2, SW1.7, U4.36 (IOT_48b)
/NRST: C10.1, J3.5, S1.2 (B), U3.7 (NRST)
/OSC_IN: C17.2, U3.5 (PH0), X1.1 (OSC)
/OSC_OUT: C20.1, U3.6 (PH1), X1.3 (OSC)
/OUT0: D5.2, J8.1, U4.25 (IOT_36b)
/OUT1: D6.2, J8.2, U4.26 (IOT_39a)
/OUT2: D7.2, J8.3, U4.27 (IOT_38b)
/OUT3: D8.2, J8.4, U4.28 (IOT_41a)
/OUT_STM: D9.2, U3.57 (PB5)
/PA0: J2.15, U3.14 (PA0)
/PA1: J2.16, U3.15 (PA1)
/PA15: J2.1, U3.50 (PA15)
/PB4: J2.6, U3.56 (PB4)
/PB9: J2.7, U3.62 (PB9)
/PC0: J2.11, U3.8 (PC0)
/PC1: J2.12, U3.9 (PC1)
/PC2: J2.13, U3.10 (PC2)
/PC3: J2.14, U3.11 (PC3)
/PC10: J2.2, U3.51 (PC10)
/PC11: J2.3, U3.52 (PC11)
/PC12: J2.4, U3.53 (PC12)
/PC13: J2.8, U3.2 (PC13)
/PC14: J2.9, U3.3 (PC14)
/PC15: J2.10, U3.4 (PC15)
/PD2: J2.5, U3.54 (PD2)
/RGB0: J10.1, U4.39 (RGB0)
/RGB1: J10.2, U4.40 (RGB1)
/RGB2: J10.3, U4.41 (RGB2)
/SPI1_MISO: JP4.1 (A), U3.22 (PA6)
/SPI1_MOSI: JP5.1 (A), U3.23 (PA7)
/SPI1_SCK: JP3.1 (A), U3.21 (PA5)
/SPI2_MISO: U3.35 (PB14), U4.6 (IOB_13b)
/SPI2_MOSI: U3.36 (PB15), U4.4 (IOB_8a)
/SPI2_NSS: U3.33 (PB12), U4.11 (IOB_20a)
/SPI2_SCK: U3.34 (PB13), U4.10 (IOB_18a)
/SWCLK: J3.2, U3.49 (PA14)
/SWDIO: J3.3, U3.46 (PA13)
/SWO: J3.4, U3.55 (PB3)
/USART1_RX: J14.2, U3.43 (PA10), U4.2 (IOB_6a)
/USART1_TX: J14.1, U3.42 (PA9), U4.3 (IOB_9b)
/USART2_RX: J13.2, U3.17 (PA3)
/USART2_TX: J13.1, U3.16 (PA2)
/USB_D+: J1.A6 (D+), J1.B6 (D+), U3.45 (PA12)
/USB_D-: J1.A7 (D-), J1.B7 (D-), U3.44 (PA11)
/VCCPLL: C6.1, C9.1, R7.1, U4.29 (VCCPLL)
GND: C1.1, C2.1, C3.1, C4.1, C5.2, C6.2, C7.2, C8.2, C9.2, C10.2, C11.2, C12.2, C13.2, C14.1, C15.2, C16.2, C17.1, C18.2, C19.2, C20.2, C21.2, C22.2, C23.2, C24.2, C25.2, C26.2, C27.2, C28.2, C29.2, C30.2, C31.2, C32.2, C33.2, C34.2, D4.1, J1.A12B1 (GND), J1.B12A1 (GND), J1.S1 (SHIELD), J3.6, J4.2, J5.2, J6.2, J15.6, J16.A12B1 (GND), J16.B12A1 (GND), J16.S1 (SHIELD), Q1.2 (S), R1.2, R3.2, R4.2, R5.2, R6.2, R8.2, R9.1, R11.1, R12.1, R13.1, R14.1, R17.2, R18.2, R23.2, R24.2, R25.2, R26.2, R27.2, R29.1, R32.1, R34.2, R35.2, R36.2, R37.2, R38.2, R41.2, S1.4 (D), S2.4 (D), U1.1 (GND), U2.1 (GND), U3.12 (VSSA), U3.18 (VSS), U3.31 (VSS), U3.47 (VSS), U3.63 (VSS), U4.49 (GND), U5.4 (GND), U6.6 (GND), U6.7 (GND), X1.2 (GND), X1.4 (GND)
unnamed: D1.1, R2.1
unnamed: D2.1, R5.1
unnamed: D3.1, R6.1
unnamed: D5.1, R23.1
unnamed: D6.1, R24.1
unnamed: D7.1, R25.1
unnamed: D8.1, R26.1
unnamed: D9.1, R27.1
unnamed: J1.A5 (CC1), R3.1
unnamed: J1.B5 (CC2), R4.1
unnamed: J16.A5 (CC1), R37.1
unnamed: J16.B5 (CC2), R38.1
unnamed: JP2.1 (A), U3.20 (PA4)
unnamed: JP6.2 (B), U4.14 (IOB_32a_SPI_SO)
unnamed: JP7.2 (B), U4.17 (IOB_33b_SPI_SI)
unnamed: JP8.2 (B), U4.15 (IOB_34a_SPI_SCK)
unnamed: JP9.2 (B), U4.16 (IOB_35b_SPI_SS)
unnamed: Q1.3 (D), R2.2
unnamed: R15.1, SW1.16
unnamed: R16.1, SW1.15
unnamed: R17.1, SW1.14
unnamed: R18.1, SW1.13
unnamed: R30.2, S3.2 (B)
unnamed: R33.2, S4.2 (B)
unnamed: C14.2, U3.30 (VCAP_1)
unnamed: D4.2, R22.2, U4.7 (CDONE)
unnamed: R28.2, U5.3 (IO2)
unnamed: R31.2, U5.7 (IO3)
unnamed: R41.1, U6.12 (CS)
unnamed: R36.1, U6.3 (SCX)
unnamed: R34.1, U6.1 (SDO/SA0)
unnamed: R35.1, U6.2 (SDX)
VBUS: C1.2, C2.2, D1.2, D3.2, J1.A9B4 (VBUS), J1.B9A4 (VBUS), J16.A9B4 (VBUS), J16.B9A4 (VBUS), U1.3 (VIN), U2.3 (VIN)

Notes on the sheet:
GPIO
POWER GENERATION
acces to FPGA flash
FPGA_IO
Programmer SWD Port
misc
I2S
IO Headers
5k1 Resistor like in this Tutorial
TODO: change UART1 to something else. We need UART1 to programm the stm
I2C
USART2
Accelero & Gyro
POWER FLAGS
note: this is not 100% correct, as there should be a 10K between 3V3 and the BOOT pin
FPGA_RGB
just make a place for 2, if there are any mistakes
STATUS LED'S
SW1 OFF: Custom Boot SW1 ON: STM Bootloader SW2 OFF: System Memory (default) SW2 ON: Embedded SRAM Boot SW3 OFF: FPGA Custom Boot SW3 ON: FPGA USB DFU Programmer SW4 OFF: FPGA Boot from Flash SW4 ON: FPGA Boot from SPI SW[5:8]: INPUT
POWER
STM USB
USART1
using the RCC MCO to output the Clock through this pin

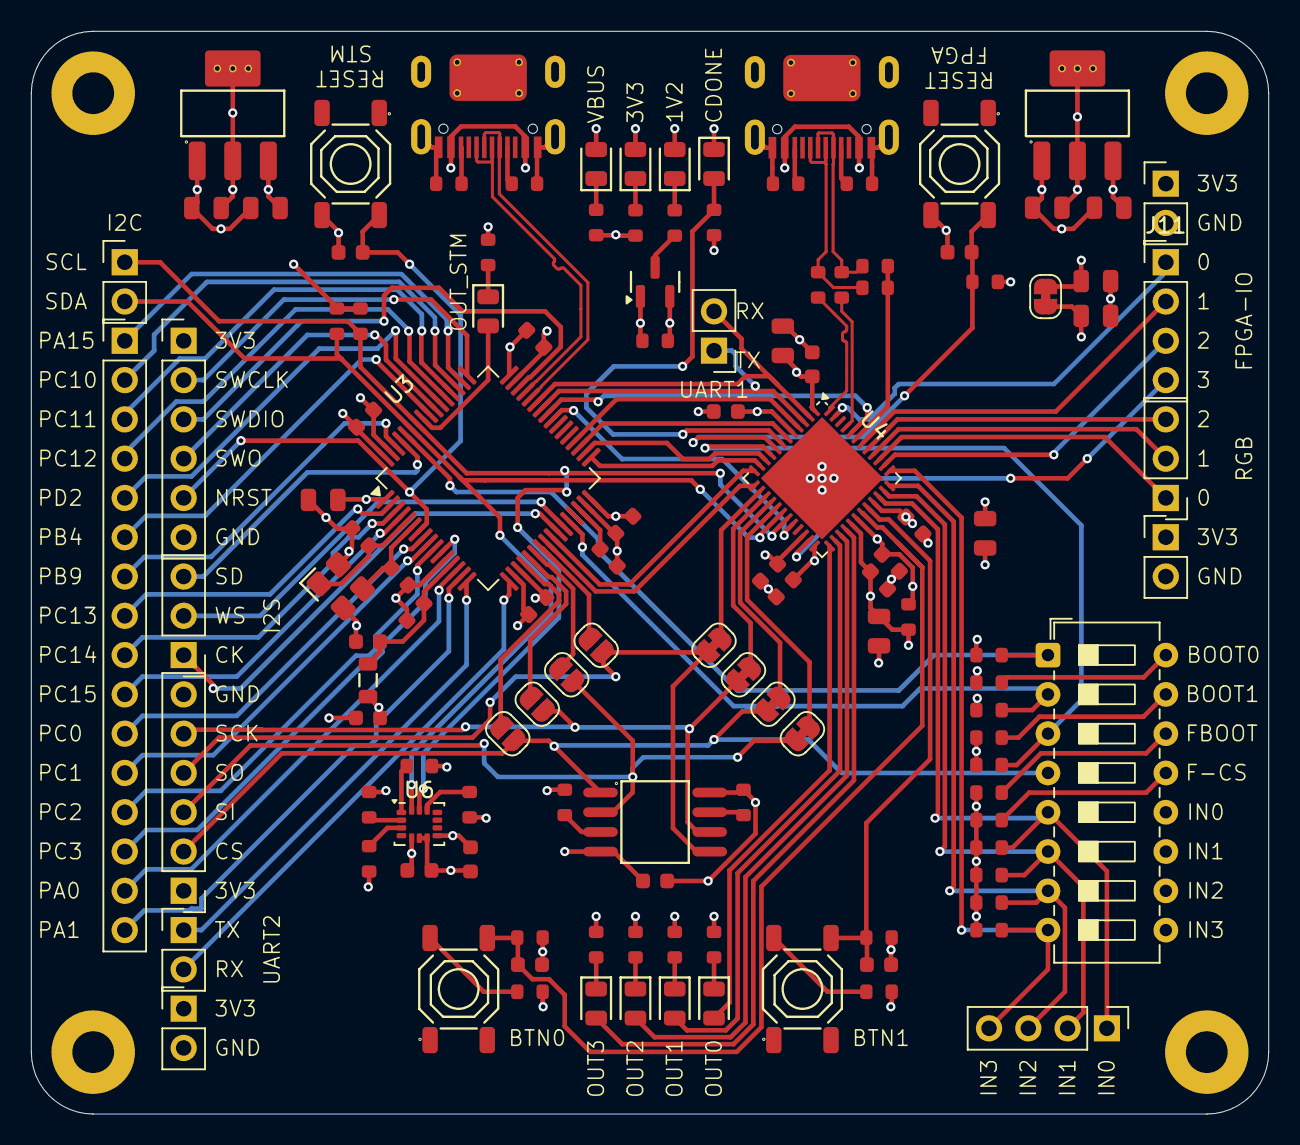
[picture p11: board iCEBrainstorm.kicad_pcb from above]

Board: 4 copper layers, 80.0 x 70.0 mm, 130 parts (1 on the bottom side), 114 nets.

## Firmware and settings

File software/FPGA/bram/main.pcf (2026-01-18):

#FPGA PINOUT DESCRIPTION

#----- CLK -----
set_io --warn-no-port clk_i 20  #16 MHz Clock, provided by the STM32

#----- Buttons -----
set_io --warn-no-port btn_0 31 #left button
set_io --warn-no-port btn_1 32 #right button

#----- Switches -----
set_io --warn-no-port in_0 34 #Input Switch and/or GPIO
set_io --warn-no-port in_1 35 #Input Switch and/or GPIO
set_io --warn-no-port in_2 36 #Input Switch and/or GPIO
set_io --warn-no-port in_3 37 #Input Switch and/or GPIO

#----- LED ------
set_io --warn-no-port out_0 25  #LED
set_io --warn-no-port out_1 26  #LED
set_io --warn-no-port out_2 27  #LED
set_io --warn-no-port out_3 28  #LED

#----- FPGA-IO ------
set_io --warn-no-port io_0 47  #GPIO
set_io --warn-no-port io_1 42  #GPIO
set_io --warn-no-port io_2 38  #GPIO
set_io --warn-no-port io_3 23  #GPIO

#----- RGB-LED ------
set_io --warn-no-port rgb_0 39 #RGB LED and/or GPIO
set_io --warn-no-port rgb_1 40 #RGB LED and/or GPIO
set_io --warn-no-port rgb_2 41 #RGB LED and/or GPIO

#----- UART ------
set_io --warn-no-port uart_tx 2  #uart output (STM RX <- FPGA TX)
set_io --warn-no-port uart_rx 3  #uart input (STM TX -> FPGA RX)

#----- I2C ------
set_io --warn-no-port scl 19 #I2C Clock
set_io --warn-no-port sda 18 #I2C Data

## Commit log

2025-10-30 init and playing around with jlcpcb plugins...
    [iCEBrainstorm.kicad_pcb, iCEBrainstorm.kicad_sch]
2025-11-02 commit from within kicad
    [iCEBrainstorm.kicad_sch]
2025-11-04 added some things to schematic
    [BOM-iCEBrainstorm.csv, bom.csv, designators.csv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]
2025-11-20 did some things
    [bom.csv, designators.csv, iCEBrainstorm.kicad_pcb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]
2025-11-23 schema und pcb gmacht, quote kostet jetzt 120$ / 10 pcs
    [bom.csv, designators.csv, iCEBrainstorm.kicad_pcb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]
2025-11-25 pascuu design review
    [iCEBrainstorm.kicad_pcb, iCEBrainstorm.kicad_sch]
2025-11-26 finalised the schematic
    [iCEBrainstorm.kicad_pcb, iCEBrainstorm.kicad_sch]
2025-11-27 still checking schematic
    [BOM-iCEBrainstorm.csv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]
2025-11-27 did some placment
    [iCEBrainstorm.kicad_pcb, iCEBrainstorm.kicad_sch]
2025-12-01 lets push
    [iCEBrainstorm.kicad_pcb, iCEBrainstorm.kicad_sch]
2025-12-01 cleared up a bit
    [iCEBrainstorm.kicad_pcb, iCEBrainstorm.kicad_sch]
2025-12-01 gekocht mit luci
    [iCEBrainstorm.kicad_pcb, iCEBrainstorm.kicad_sch]
2025-12-02 wider mit luci gekocht
    [iCEBrainstorm.kicad_pcb, iCEBrainstorm.kicad_sch]
2025-12-06 did some lines + added a IN connector :)
    [iCEBrainstorm.kicad_pcb, iCEBrainstorm.kicad_sch]
2025-12-07 did back silkscreen design
    [iCEBrainstorm.kicad_pcb]
2025-12-10 added uart1 connector, added power connectors, added schema back silkscreen symbol
    [iCEBrainstorm.kicad_pcb, iCEBrainstorm.kicad_sch]
2025-12-11 did some routing
    [bom.csv, designators.csv, iCEBrainstorm.kicad_pcb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]
2025-12-11 preparing for order, need to change some components...
    [BOM-iCEBrainstorm.csv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]
2025-12-11 send to production, note that the SM6DS3TR got replaced with the LSM6DSRTR for cost reasons.
    [BOM-iCEBrainstorm.csv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]
2025-12-29 added STM and FPGA Code, added bootloader binairy, did more documentation
    [iCEBrainstorm.kicad_sch]
2026-01-06 added no2bootloader as submodule and added documentation on how to buzild the bootloader and flash the SPI flash
2026-01-28 changed the STM USB-UART Bridge
2026-02-11 updated readme: added stm32 project setup tutorial
2026-02-23 init bram example, didn't work so far
    [main.pcf]
